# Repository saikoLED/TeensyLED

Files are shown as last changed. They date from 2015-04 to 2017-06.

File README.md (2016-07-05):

TeensyLED Controller
====================
Copyright Brian Neltner 2015<br/>
Version 0.4 - May 21, 2015

Summary
-------
This provides a basic library and example code for interacting
with a RGBW LED light using Hue, Saturation, and Intensity (HSI)
mode. Also provided are a basic USB interface example, and an example
for using the fully isolated DMX interface.

CircuitHub design created for this board with pre-identified working
parts. Licensed under CERN Open Hardware license (http://www.ohwr.org/projects/cernohl) which
allows for anyone to copy, modify and distribute this design (and products manufactured therefrom) so long
as they are licensed under identical terms & maintain all copyrights.

https://circuithub.com/projects/neltnerb/TeensyLED

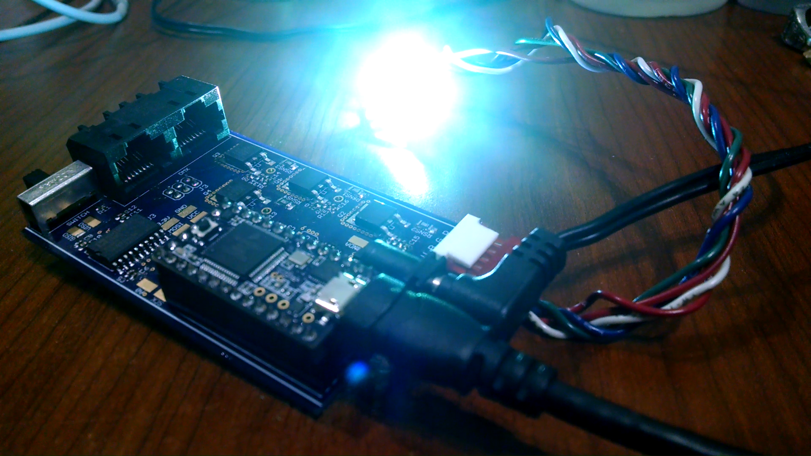
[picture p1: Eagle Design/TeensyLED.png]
Board Image


Software Features
-----------------
- HSI to RGBW library for interacting with LED sources with color correction.
- PID based fader that follows a random walk through colorspace.
- Tested basic DMX receiving software (just prints DMX data to USB Serial port for now).
- Basic debug example to set the brightness from the USB port.

For more information about the HSI Colorspace developed by SaikoLED
please check out:
- [Why every LED light should be using HSI colorspace.](http://blog.saikoled.com/post/43693602826/why-every-led-light-should-be-using-hsi)
- [How to convert from HSI to RGB+white.](http://blog.saikoled.com/post/44677718712/how-to-convert-from-hsi-to-rgb-white)
- [Implementing arbitrary color correction with the myki!](http://blog.saikoled.com/post/45630908157/implementing-arbitrary-color-correction-with-the)
- [Talk about HSI Colorspace and RGBW](http://blog.saikoled.com/post/71708131057/talk-about-hsi-colorspace-and-rgbw)

If you are curious about our other projects, you can visit our [blog](http://blog.saikoled.com).

Hardware Features
-----------------

[Schematics and Board Drawings](Eagle Design/TeensyLED.pdf)

- Teensy 3.1 socket.
- RJ45-based DMX Connectors as per DMX-512A.
- Fully isolated DMX-compatible RS485 Interface (ADM2582E).
- Header to switch polarity of DMX signal for compatibility.
- 4x 700mA BJT based current sinks (670-730mA typical).
- Current sinks capable of driving 700mA with 75ns pulse widths.
- 75nm pulse width allows 16-bit PWM at 183Hz, or 8-bit PWM at very fast. 16-bit PWM possible at higher PWM frequencies, but with increased non-linearity for low codes. See Simulations directory for more detail on theoretical performance.
- 5-24VDC board compatibility, with the Vin routed directly to LED V+. Up to 5A allowed by CP-202AH-ND barrel plug connector. Voltage limit is due to barrel plug connector, up to 48VDC can be wired directly using the available test point.
- Built in high efficiency switching regulator to provide 3.7VDC.
- Designed to fit into Hammond 1455C801 Extruded Aluminum Enclosure.
- 8-pin expansion header to access 3.3V, GND, DAC, A0 (SCK), A1/A2 (Touch), and DIN/DOUT (SPI/USART).
- PTC Fuse to prevent damage from shorts or over-power.
- Reverse protection diodes on power inlet and flyback diodes on each LED output to prevent reverse bias.

Hardware Performance
--------------------
Simulations have been done on the current sinking circuitry in order to optimize the response time and stability, and real measurements demonstrate comparable performance. Simulations were done using LTSpice and the vendor supplied model for the ZXT1053AK. These simulations are limited in predicting real performance, particularly in the realm of thermal issues.

###Circuit Model
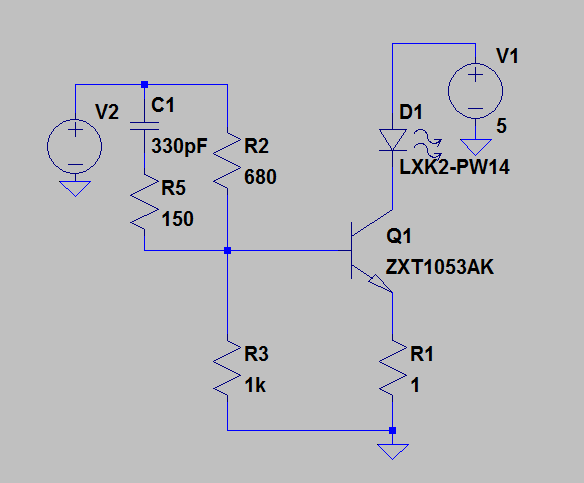
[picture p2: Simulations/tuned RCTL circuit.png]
Circuit Schematic


###Current Output with 1μs pulse.
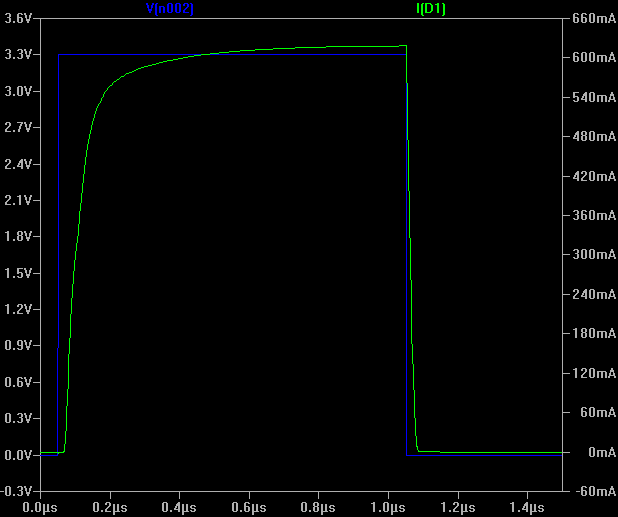
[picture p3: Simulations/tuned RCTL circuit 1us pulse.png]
1μs Pulse Width


###Current Output with 100ns pulse.
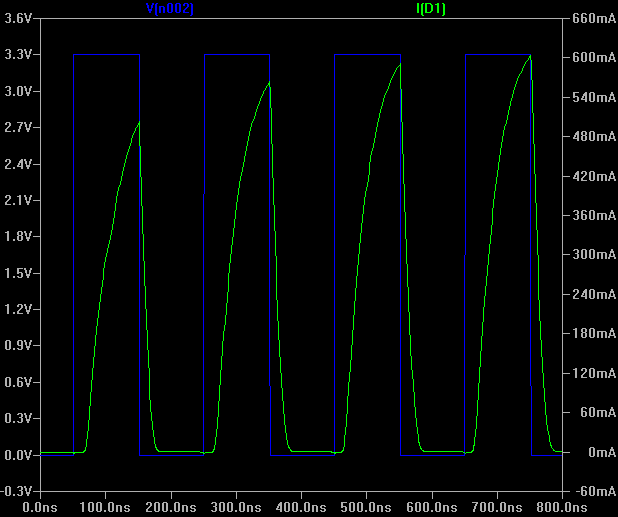
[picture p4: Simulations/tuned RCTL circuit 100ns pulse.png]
100ns Pulse Width


###Estimated current load from controller pin.
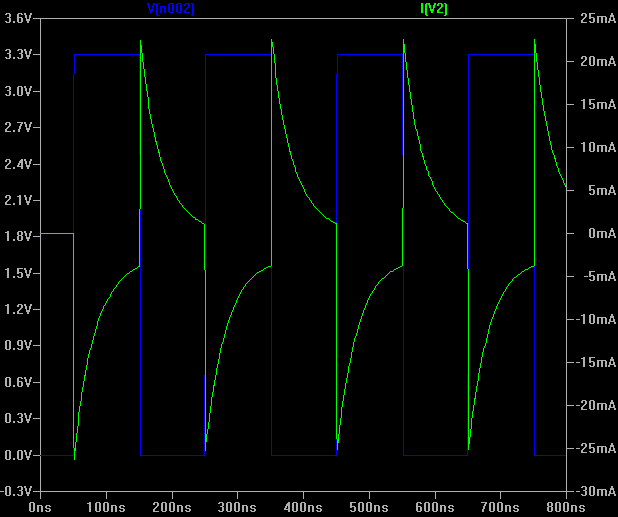
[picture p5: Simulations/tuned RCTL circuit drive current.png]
Drive Current


Major Hardware Limitations
--------------------------
- Heat dissipation at the BJTs is the primary limiting factor on maximum power. Switching regulators
are unfortunately inappropriate for such high speed PWM capabilities.
  - Although the BJTs chosen are rated to 4.4W each, at 700mA and a
    typical minimum drop from the top of the BJT to ground of 3V for
    good regulation, power dissipation throughout the board is likely
    to be a bare minimum of 2.1W per channel fully on.
  - I think that if you operate the system in HSI mode, where the
    total current sent to the LEDs is limited to 700mA, split between
    the various channels to change colors, you can probably get away
    with as much as 4W from that subsystem. This is power lost in the
    current sink itself, the power of the LEDs is unimportant.
  - This limits the voltage you can have between the *bottom* of your
    LED chain (no matter how long it is) and ground to under *5VDC*.
  - I am thinking about a new design that will automatically regulate
    down the voltage at the top of the LEDs to the minimum needed
    for reliable regulation based on feedback, but this is a work in
    progress. Perhaps for version 2.0.
- High current and high frequency PWM may radiate excessively for FCC. There is a ferrite bead to improve FCC compatibility, but the wiring between this board and the LEDs will be a significant radiator and must be done with care if the result is intended for sale.
- High current and frequency PWM may degrade ADC measurements, especially from high-
    impedance sources.

License
-------
All software, hardware designs, and hardware design files are licensed
under the GPL.

> TeensyLED Controller is free software and hardware: you can redistribute
> it and/or modify it under the terms of the GNU General Public License
> as published by the Free Software Foundation, either version 3 of the
> License, or (at your option) any later version.
> 
> TeensyLED Controller is distributed in the hope that it will be useful,
> but WITHOUT ANY WARRANTY; without even the implied warranty of
> MERCHANTABILITY or FITNESS FOR A PARTICULAR PURPOSE.  See the
> GNU General Public License for more details.
> 
> You should have received a copy of the GNU General Public License
> along with TeensyLED Controller.  If not, see <http://www.gnu.org/licenses/>.

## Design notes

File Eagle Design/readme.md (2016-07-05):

Board Design files for TeensyLED (EagleCad).

CircuitHub populated design that you may use to produce copies of this board.
https://circuithub.com/projects/neltnerb/TeensyLED

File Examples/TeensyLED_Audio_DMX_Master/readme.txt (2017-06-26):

TeensyLED Audio DMX Master
Version 0.9
Copyright Brian Neltner 2016

Video Example Demonstrating Algorithm Functionality with Color Kinetics ColorBlast 12.
https://www.youtube.com/watch?v=BOnsDaA30Ak

Description:

This program is designed for use with the SaikoLED TeensyLED Driver
system, using the ADM2582E from Analog Devices to provide a fully
isolated RS485/DMX-512 interface which has been demonstrated as both
a DMX master and DMX slave device.

TeensyLED Board Design Files (EagleCAD) and some other libraries can
be found at:
https://github.com/saikoLED/TeensyLED

A jumper is available on the TeensyLED board to allow switching between
the formal DMX-512a spec for DMX over RJ45/CAT5 cabling and the Color
Kinetics version of the standard, which switches DATA- and DATA+ and the
shield/ground connections.

Reference:
https://en.wikipedia.org/wiki/DMX512#RJ-45_pinout

This program assumes that line level audio (~1V peak-to-peak) is
available, and wired to analog input 0 on the Teensy 3.1 (on the
TeensyLED, this is available on JP1. In this example, A0 is connected
to 3.3V and GND via 100k resistors to provide a mid-scale DC offset
and then a capacitor is used to connect the audio input to AO.

As such, you end up with a capacitively coupled audio signal centered
at mid-scale. There are other ways to accomplish this with higher
fidelity, but for this purpose the audio quality is not particularly
important as it is never output to speakers and is only used for
controlling the lighting.

The basic algorithm below utilizes the SaikoLED HSI to RGB system to
convert a hue-saturation-intensity color to RGB which is then output
to standard RGB lighting. RGBW lighting could be used by switching
to the SaikoLED HSI->RGBW code, or using the new full CIE color
correction algorithm specifically designed to allow the TeensyLED to
control many-wavelength devices such as the LEDEngin LZ7 series LED
that provides RAGCBVW LEDs.

LEDEngin LZ7 LED and CIE Color Correction.
http://blog.saikoled.com/post/133625978643/full-cie-color-correction-with-the-teensy-31

For this audio analysis effect, the hue of the LED light is constantly
rotating, with beat detection utilized to cause pulses in the lighting.
Volume normalization is accomplished by saving the maximum audio signal
seen when the signal exceeds the prior maximum, but then gradually
letting the max signal level decay back to a low value over time so that
it can both immediately respond to volume increases, and recognize
when the audio has gotten quieter.

This effect also accomplishes automatic thresholding for the derivitive
of the audio signal for beat detection -- you select a target estimate
for the number of beats per second you'd like to see, and it gradually
tunes the threshold to the actual audio received to achieve roughly that
number of detection events. This works effectively to allow the user
to switch between very different music genres without needing to reprogram
a pile of magic constants to get it to look good.

Upon beat detection, the intensity of the lights immediately increases to
the normalized volume seen during that beat. As such, a loud beat in a soft
section of music will cause the light to flash brightly while a soft beat
in a loud section will appear more as a subtle flash. This results in a 
very nice effect wherein a loud beat followed by several soft accent beats
(very common in music of all kinds) shows the complexities of the beat
pattern very intuitively.

After a beat detection, the light brightness gradually decays -- the light
turning on is immediate but the decay takes ~100ms which gives a nice shape
that matches most drum signals very naturally. This decay time also varies
automatically based on the number of beats in the song. If a song has many
many beats the decay time is short so that the beats appear visually cleaner
to match the feeling of the music.

In this example code, I demonstrate controlling 8 DMX lights which are
arranged in a color wheel so that the entire array rotates around while
pulsing synchronously.

This rough algorithm was first demonstrated in 2013:
http://blog.saikoled.com/post/44823088119/myki-prototype-with-direct-audio-analysis
and the improved algorithm below was first demonstrated in 2016 at the
Firefly Arts Festival.

This software requires the DmxSimple library which uses bit-banging of
DMX outputs and does not support RDM or other advanced DMX features.
However, the ADM2582E and Teensy 3.1 should be perfectly capable of using
these features if a better library becomes available.

Filtering is used throughout this code, using explonential smoothing as a
very fast and simple way to accomplish a low-pass filter.

Reference:
https://en.wikipedia.org/wiki/Exponential_smoothing

An example is:

audioZero = 0.999999*audioZero + 0.000001*audioSignal;

which takes the prior zero and mixes it with the instantaneous
audio value to get a low-pass filtered zero. The two constants must
always add to one, but the larger the 0.000001 value is the more
quickly the filtered version will adjust to changes.

I am not good at C flags, but there are commented out serial communication
lines that can be uncommented for debug information (for instance, printing
the audio RMS values and beat detection values for tuning and debugging
audio signal issues). Some of this should probably be better encapsulated
in a C++ style class to reduce the unabstracted complexity of the effects.

Released under MIT License:

Copyright (c) 2016 Brian Neltner

Permission is hereby granted, free of charge, to any person obtaining a copy
of this software and associated documentation files (the "Software"), to deal
in the Software without restriction, including without limitation the rights
to use, copy, modify, merge, publish, distribute, sublicense, and/or sell
copies of the Software, and to permit persons to whom the Software is
furnished to do so, subject to the following conditions:

The above copyright notice and this permission notice shall be included in all
copies or substantial portions of the Software.

THE SOFTWARE IS PROVIDED "AS IS", WITHOUT WARRANTY OF ANY KIND, EXPRESS OR
IMPLIED, INCLUDING BUT NOT LIMITED TO THE WARRANTIES OF MERCHANTABILITY,
FITNESS FOR A PARTICULAR PURPOSE AND NONINFRINGEMENT. IN NO EVENT SHALL THE
AUTHORS OR COPYRIGHT HOLDERS BE LIABLE FOR ANY CLAIM, DAMAGES OR OTHER
LIABILITY, WHETHER IN AN ACTION OF CONTRACT, TORT OR OTHERWISE, ARISING FROM,
OUT OF OR IN CONNECTION WITH THE SOFTWARE OR THE USE OR OTHER DEALINGS IN THE
SOFTWARE.

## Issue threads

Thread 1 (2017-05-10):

Question ADM2582

kasperkamperman, 2017-05-10:
Hi,
Nice design. Maybe I'd like to make a similar kind of board for the Particle Photon. I was wondering why you have selected the ADM2582 and not the ADM2587. From what I can see in the datasheet the 2582 has a dataspeed of 16Mbps and the 2587 a dataspeed of 500kbps.

For DMX 500kbps will be sufficient I think because of the speed of 250000baud (250kbps).

Or do I miss something?

Thanks in advance for your feedback.

neltnerb, 2017-05-10:
Hi Kasper,

Yes! Please, the Photon looks great to me. I've built wifi lights before
since 2010:

http://www.instructables.com/id/Ultra-bright-LED-Color-Changing-Spotlight-using-Op/

but the photon looks like a way easier way to do it than what I've tried
before. I actually have a photon sitting on my desk that I just haven't
gotten around to modifying the TeensyLED board to handle. It shouldn't be
too challenging though, I think you should find it to not be a big problem.
I hope you share your design so that others can use it as well!

You may find helpful thinking about one thing ahead of time, which is wifi
latency. In my instructable project above, it is using a wifi chip running
on a local network, and even with only local communication with more than
about eight lights the latency became a problem. Lots of wifi devices on
one network has a lot of issues where one light will just sort of stop
getting updates for a bit and then start up again.

The biggest reason I have not yet tried the Photon for it is that because
the network is non-local (you, I believe, connect via their cloud service)
I can't make it work in remote locations like Burning Man and the latency
is much higher as the command to change colors has to traverse the internet
to make it to your lamp even if it's in the same room as you. I think you
can make the Photon communicate locally, but it didn't look as
straightforward as I had hoped.

There are two decent ways to work around this -- the first is to have a
single photon or only a few photons acting as DMX to WiFi Transceivers
which then send actual DMX commands out to a local network over physical
wires. This avoids wireless contention at least, and keeps at least the
lights on a single DMX universe synchronized. The second is to make the
lights very smart, and send them only very abstract commands like "do a
color wheel at this speed, saturation, and intensity" so that the amount of
data being sent to them is very small. Basically highly compressed data
rather than just an RGB color. Either approach works well, but you should
keep in mind both wireless contention and latency (particularly if it is
dealing with a non-local sever).

But I think you can do it! Please keep me updated, I would love to hear how
it goes!

With regards to the selection of the ADM2582E over the ADM2587E, I think
you are correct that the ADM2587E will work fine for DMX. I can't recall
for sure after the intervening years, but most likely the ADM2587E was out
of stock at the time so I just used the ADM2582E. I do not think there is
any reason it would not work just fine with the ADM2587E. There may even be
more appropriate chips now that it's three years later!

On Wed, May 10, 2017 at 3:24 AM, kasperkamperman <notifications@github.com>
wrote:

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

--
Brian Neltner, Ph.D.
President, SaikoLED
neltnerb@saikoled.com

kasperkamperman, 2017-05-11:
Hi Brian,

Thanks for the extensive response. I'm aware of the limitations of the Photon. Their main purpose is IoT, but you can use them in a local network as well (UDP/TCP). Latency with these kind of devices is always a problem. Although there is someone that build a ArtNet node with 8 universes with the STM32 processor (although it's a M4 variation and not the M3 as on the Photon) http://www.ulrichradig.de/home/index.php/dmx/8-kanal-art-net

My goal is however to generate DMX and effects on the Photon board itself (probably by using [FastLED](http://fastled.io) . I need to make a stable DMX output, but I found already some good implementations that I can use.

Of course I'll share the design and the library. If you'd like to follow along: https://community.particle.io/t/transmit-dmx-data-with-dma-on-serial1/32581

Another question. I see that you power the chip with 3.3V. I assumed that 5V was necessary. I was trying to find what the signal voltage of DMX is, since they follow the RS485 standard for the physical layer I think a difference of 200mV on the signal lines still gives a reliable data transmission (if I interpret the datasheet fine). I was wondering if 3.3V might do for long cable lengths because of cable resistance.

neltnerb, 2017-05-11:
Hi Kasper!

Sounds fabulous, I'm not sure I'd be able to help much with the DMX
code, but there are some good reference libraries.

I'm not myself a particularly skilled programmer, but you might check
out the actual reference implementations for DMX which exist for
several ARM processors.

http://www.nxp.com/documents/application_note/AN10717.pdf

for instance. NXP has several chips that they have application notes
and example code for DMX including RDM. I don't think I'd be capable of
porting it, but perhaps you can!

The signal voltage for DMX is the same as the signal voltage for RS485,
balanced +/- 200mV. The reason I picked the ADM2582E is because it has
a built in isolated voltage transformer to power the isolated half
without needing additional transformers, so it produces the 200mV
signal level internally. No need to think much about it.

The 3.3V sets the interface voltage, so I matched the interface voltage
expected by the Teensy board. So just match whatever the Photon expects
(probably 3.3V). It will generate it's own transceiver voltages.

The interface being isolated from the board grounds is pretty critical.
If you don't do it you end up with horrific ground loops if you have
multiple lights connected to different voltage grounds. A lot of cheap
commercial LED fixtures don't do this properly and it causes I'd say
the majority of communications failures in installations.

But check out my eagle files for how to make sure the ground planes are
separated, if you connect the grounds between the RS485 and the rest of
the board it will defeat the purpose of using the ADM2582E because it
will just re-connect the grounds and re-create the ground loops.

I'll also warn you that Color Kinetics fixtures use a non-standard DMX
wiring layout. It's mentioned in the wikipedia page I believe but
you'll need a way to switch between the two pinouts if you want to use
both them and devices implementing the official standard.

kasperkamperman, 2017-05-12:
Thanks!

Closed 2017-05-12.

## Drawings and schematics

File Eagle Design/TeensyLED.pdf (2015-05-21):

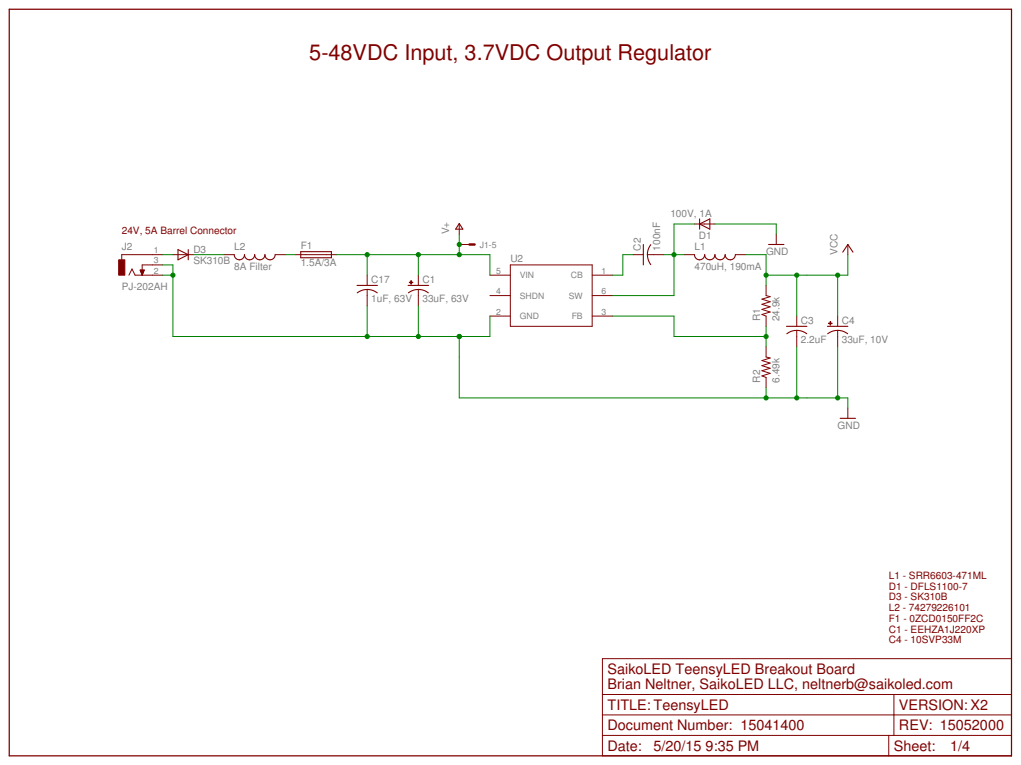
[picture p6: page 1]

SaikoLED TeensyLED Breakout Board
Brian Neltner, SaikoLED LLC, neltnerb@saikoled.com

TITLE: TeensyLED | VERSION: X2
Document Number: 15041400 | REV: 15052000
Date: 5/20/15 9:35 PM | Sheet: 1/4

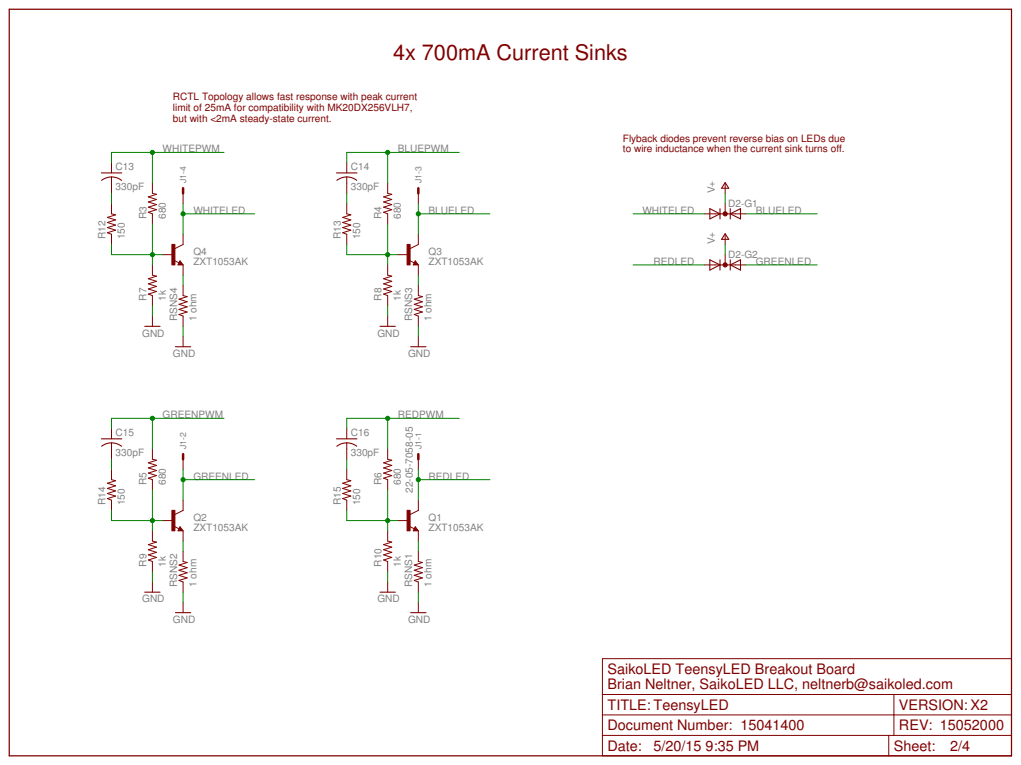
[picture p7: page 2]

RCTL Topology allows fast response with peak current

to wire inductance when the current sink turns off.

SaikoLED TeensyLED Breakout Board
Brian Neltner, SaikoLED LLC, neltnerb@saikoled.com

TITLE: TeensyLED | VERSION: X2
Document Number: 15041400 | REV: 15052000

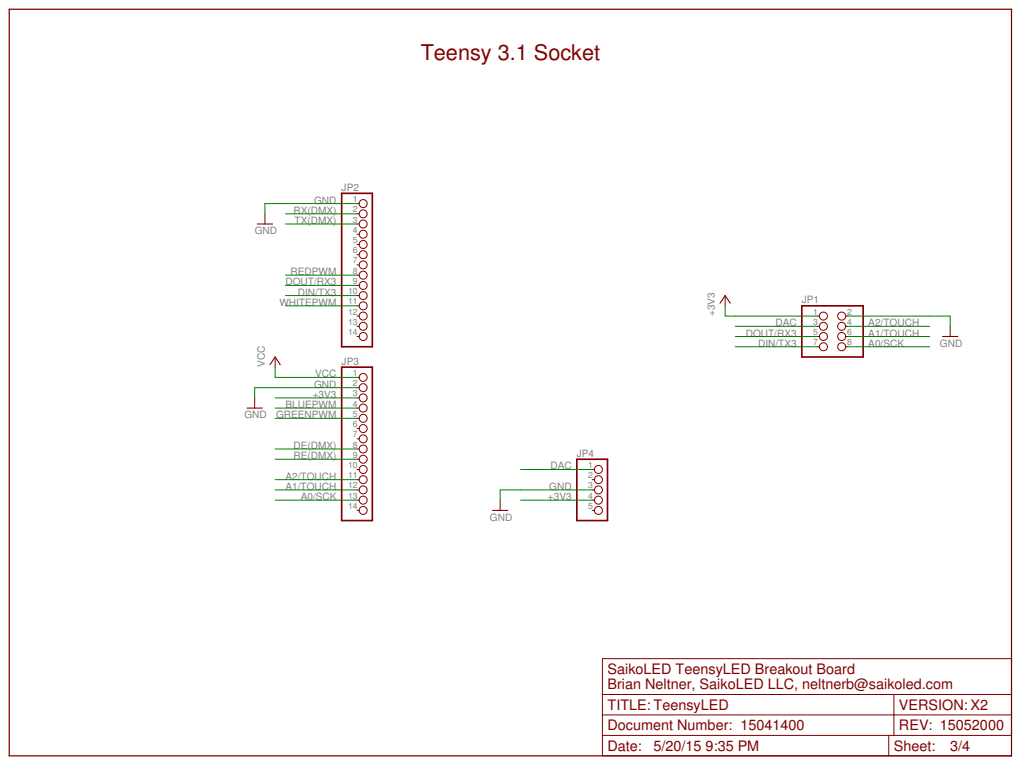
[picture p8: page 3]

SaikoLED TeensyLED Breakout Board
Brian Neltner, SaikoLED LLC, neltnerb@saikoled.com

TITLE: TeensyLED | VERSION: X2
Document Number: 15041400 | REV: 15052000

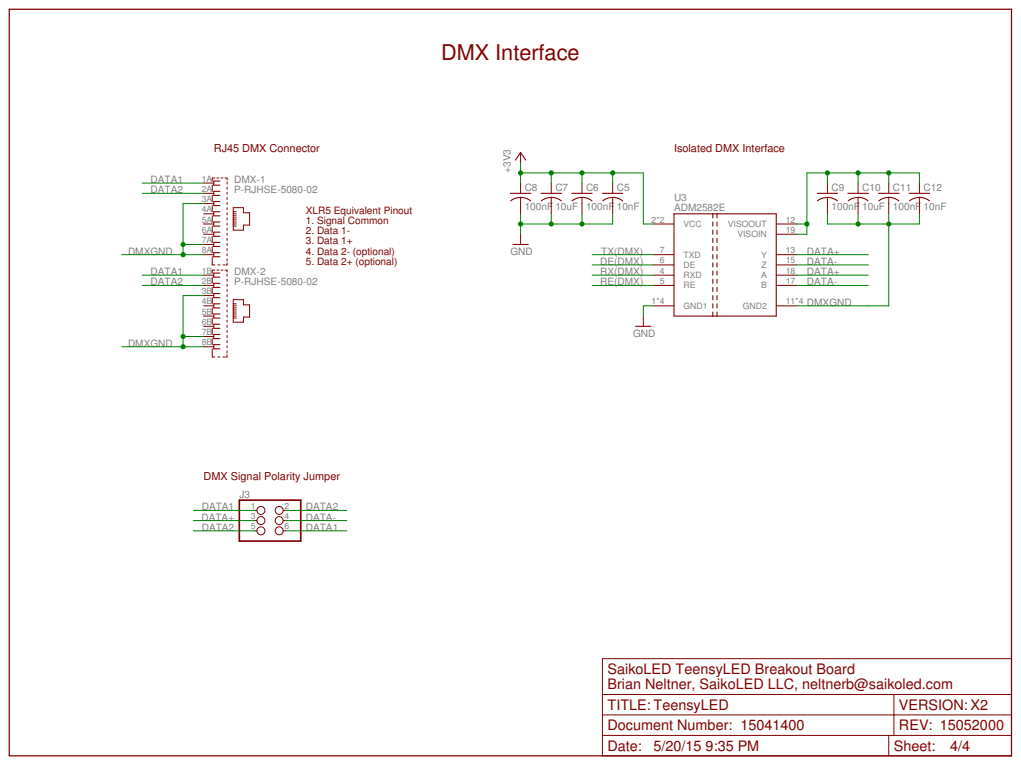
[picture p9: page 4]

DMX Signal Polarity Jumper

SaikoLED TeensyLED Breakout Board
Brian Neltner, SaikoLED LLC, neltnerb@saikoled.com

TITLE: TeensyLED | VERSION: X2
Document Number: 15041400 | REV: 15052000

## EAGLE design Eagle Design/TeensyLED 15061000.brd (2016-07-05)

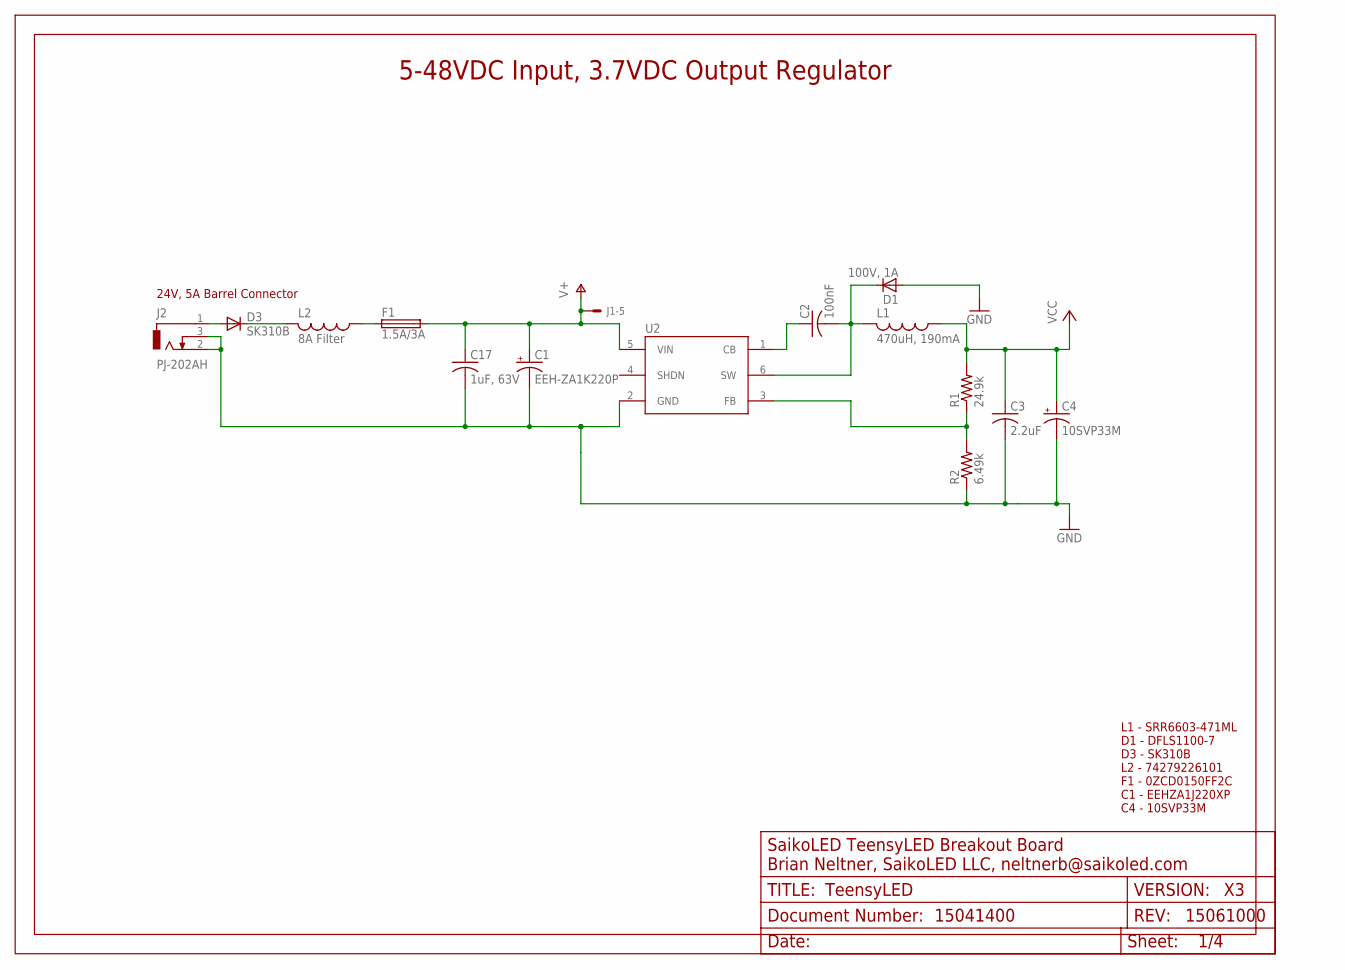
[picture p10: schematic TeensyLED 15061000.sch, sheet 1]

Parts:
C1: EEH-ZA1K220P; PANASONIC_F
C2: 100nF; C0805K
C3: 2.2uF; C0402PRO; MPN MCLV4R7M1HB-0513-RH
C4: 10SVP33M; PANASONIC_B
C17: 1uF, 63V; C0805K; MPN MCLV4R7M1HB-0513-RH
D1: 100V, 1A; DFLS1100
D3: SK310B; SMB
F1: 1.5A/3A; 2920
FRAME1: LETTER_LNOSILK; EMPTY
J1: 22-05-7058-05; 7395-05
J2: PJ-202AH
L1: 470uH, 190mA; SRR6603
L2: 8A Filter; L1812
R1: 24.9k; R0402PRO; MPN BLU0402-9762-BT25W
R2: 6.49k; R0402PRO; MPN ERJ-3EKF4123V
U2: LMR16006YDDCT; DDC0006A; MPN MCF 0.25W 1K

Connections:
GND: C1.-, C3.2, C4.-, C17.2, D1.A, J2.2 (3), J2.3 (2), R2.1, U2.2 (GND); also elsewhere on the board
unnamed: C2.1, U2.1 (CB)
unnamed: F1.P$1 (1), L2.1
unnamed: R1.1, R2.2, U2.3 (FB)
unnamed: D3.C, L2.2
unnamed: D3.A, J2.1
V+: C1.+, C17.1, F1.P$2 (2), J1.5, U2.5 (VIN); also elsewhere on the board
VCC: C3.1, C4.+, L1.P$1 (1), R1.2; also elsewhere on the board
VSW: C2.2, D1.C, L1.P$2 (2), U2.6 (SW)

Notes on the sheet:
5-48VDC Input, 3.7VDC Output Regulator
24V, 5A Barrel Connector
L1 - SRR6603-471ML D1 - DFLS1100-7 D3 - SK310B L2 - 74279226101 F1 - 0ZCD0150FF2C C1 - EEHZA1J220XP C4 - 10SVP33M

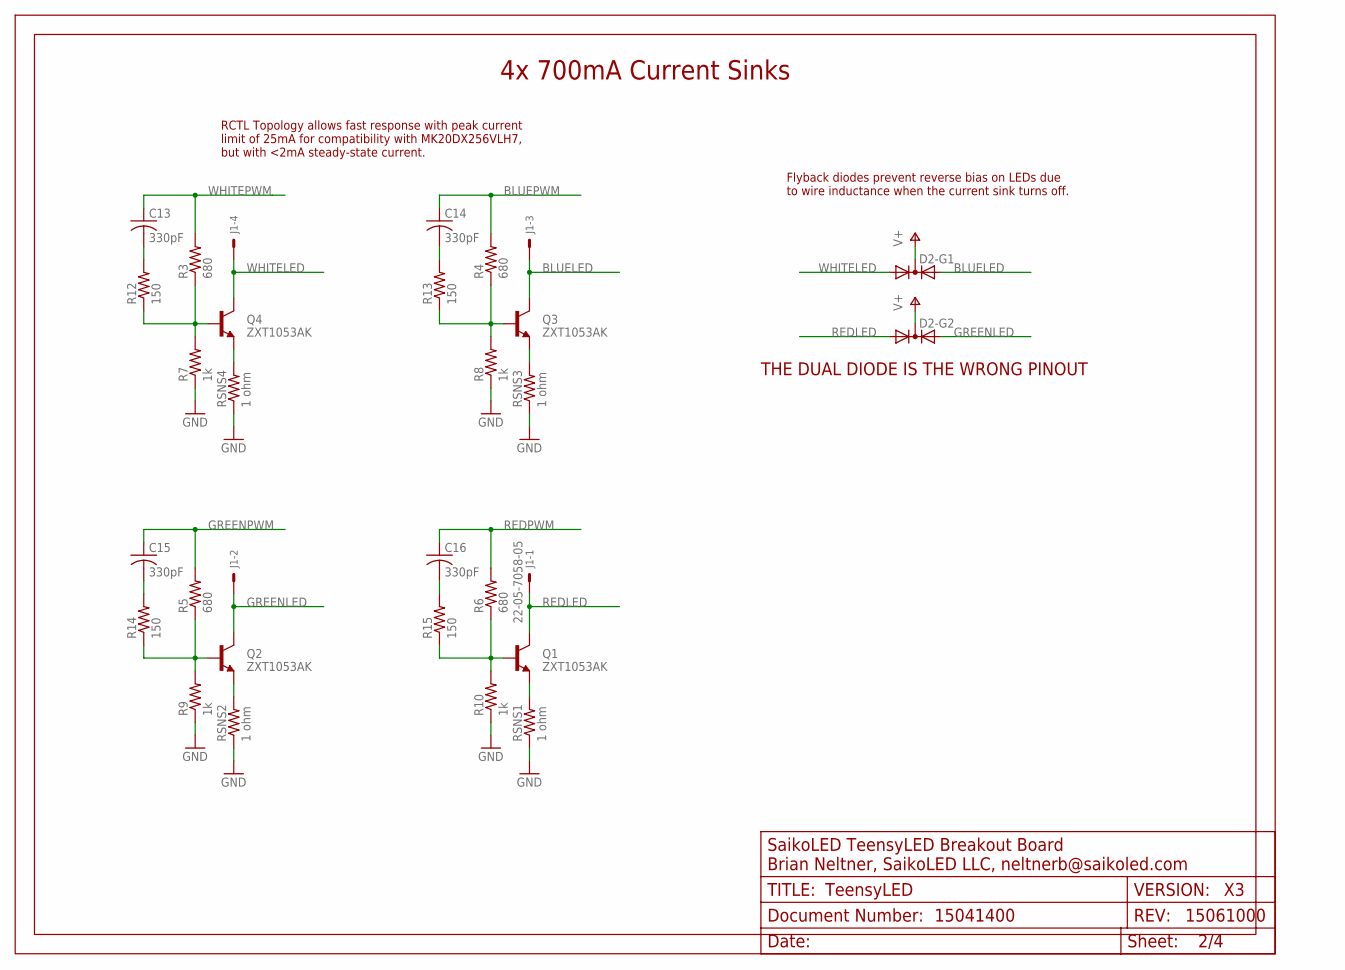
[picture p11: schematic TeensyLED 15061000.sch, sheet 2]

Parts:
C13, C14, C15, C16: 330pF; C0402PRO
D2: DUAL_DIODE_AC-CA-SOT363; SOT363_PHILIPS
FRAME2: LETTER_LNOSILK; EMPTY
J1: 22-05-7058-05; 7395-05
Q1, Q2, Q3, Q4: ZXT1053AK; TO252
R3, R4, R5, R6: 680; R0402PRO
R7, R8, R9, R10: 1k; R0402PRO
R12, R13, R14, R15: 150; R0402PRO
RSNS1, RSNS2, RSNS3, RSNS4: 1 ohm; R1206

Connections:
BLUELED: D2.3 (A2), J1.3, Q3.C
BLUEPWM: C14.1, R4.2; also elsewhere on the board
GND: R7.1, R8.1, R9.1, R10.1, RSNS1.1, RSNS2.1, RSNS3.1, RSNS4.1; also elsewhere on the board
GREENLED: D2.4 (A2), J1.2, Q2.C
GREENPWM: C15.1, R5.2; also elsewhere on the board
unnamed: Q2.E, RSNS2.2
unnamed: Q4.E, RSNS4.2
unnamed: Q3.E, RSNS3.2
unnamed: Q1.E, RSNS1.2
unnamed: Q2.B, R5.1, R9.2, R14.1
unnamed: Q4.B, R3.1, R7.2, R12.1
unnamed: Q1.B, R6.1, R10.2, R15.1
unnamed: C13.2, R12.2
unnamed: C14.2, R13.2
unnamed: C15.2, R14.2
unnamed: C16.2, R15.2
R23: Q3.B, R4.1, R8.2, R13.1
REDLED: D2.6 (A1), J1.1, Q1.C
REDPWM: C16.1, R6.2; also elsewhere on the board
V+: D2.2 (K), D2.5 (K); also elsewhere on the board
WHITELED: D2.1 (A1), J1.4, Q4.C
WHITEPWM: C13.1, R3.2; also elsewhere on the board

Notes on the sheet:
4x 700mA Current Sinks
RCTL Topology allows fast response with peak current limit of 25mA for compatibility with MK20DX256VLH7, but with <2mA steady-state current.
Flyback diodes prevent reverse bias on LEDs due to wire inductance when the current sink turns off.
THE DUAL DIODE IS THE WRONG PINOUT

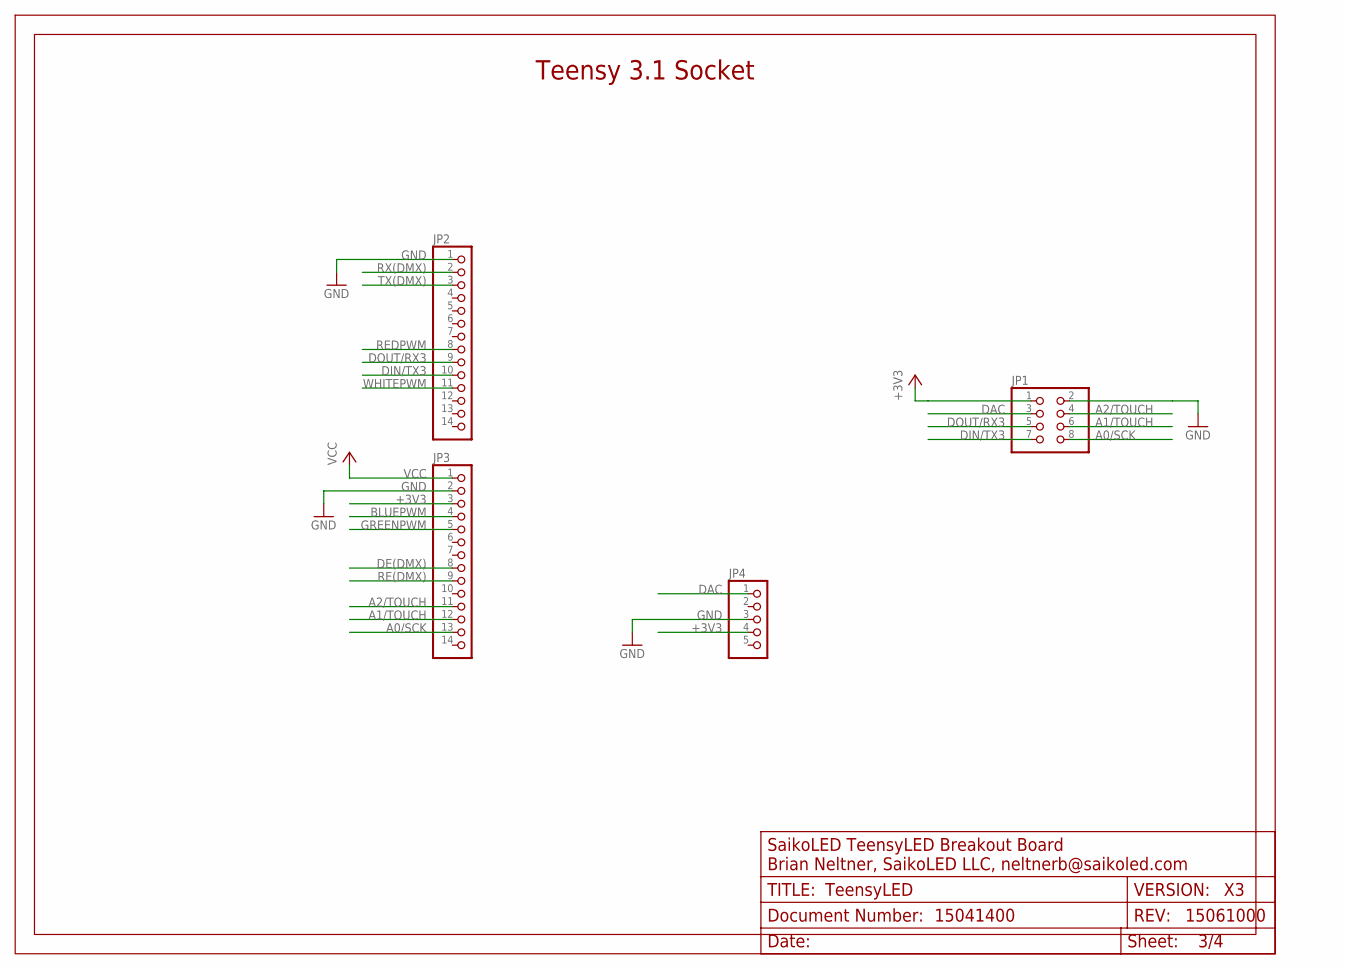
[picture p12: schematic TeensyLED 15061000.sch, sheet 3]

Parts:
FRAME3: LETTER_LNOSILK; EMPTY
JP1: PINHD-2X4; 2X04
JP2, JP3: PINHD-1X14/ROUND; 1X14/ROUND
JP4: PINHD-1X5/ROUND; 1X05/ROUND

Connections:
+3V3: JP1.1, JP3.3, JP4.4; also elsewhere on the board
A0/SCK: JP1.8, JP3.13
A1/TOUCH: JP1.6, JP3.12
A2/TOUCH: JP1.4, JP3.11
BLUEPWM: JP3.4; also elsewhere on the board
DAC: JP1.3, JP4.1
DE(DMX): JP3.8; also elsewhere on the board
DIN/TX3: JP1.7, JP2.10
DOUT/RX3: JP1.5, JP2.9
GND: JP1.2, JP2.1, JP3.2, JP4.3; also elsewhere on the board
GREENPWM: JP3.5; also elsewhere on the board
RE(DMX): JP3.9; also elsewhere on the board
REDPWM: JP2.8; also elsewhere on the board
RX(DMX): JP2.2; also elsewhere on the board
TX(DMX): JP2.3; also elsewhere on the board
VCC: JP3.1; also elsewhere on the board
WHITEPWM: JP2.11; also elsewhere on the board

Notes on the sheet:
Teensy 3.1 Socket

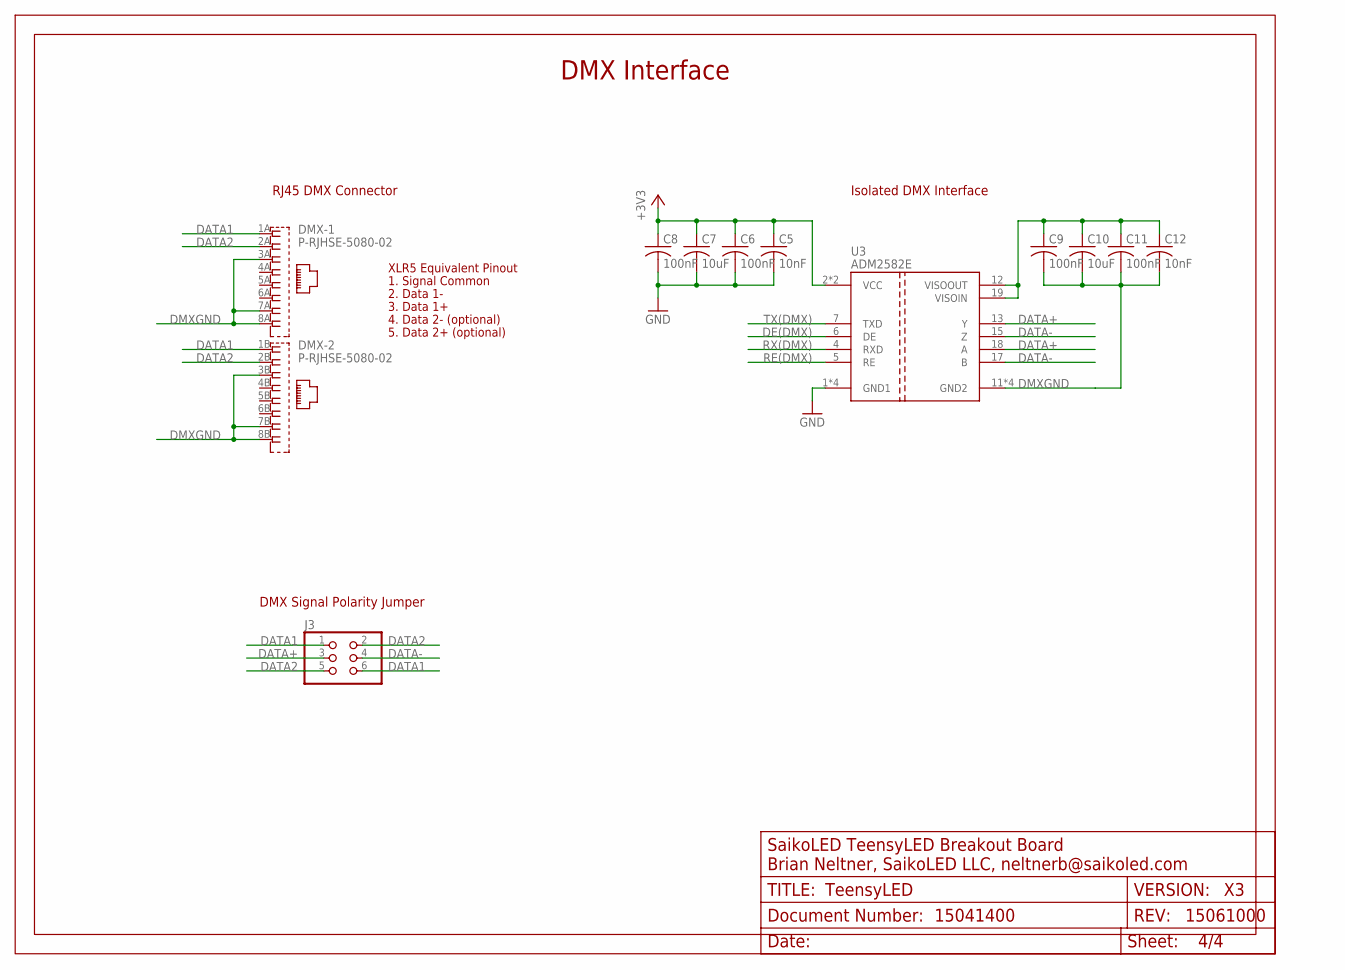
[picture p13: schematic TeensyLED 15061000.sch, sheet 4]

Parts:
C5, C12: 10nF; C0402PRO
C6, C8, C9, C11: 100nF; C0402PRO
C7, C10: 10uF; C0402PRO
DMX: P-RJHSE-5080-02
FRAME4: LETTER_LNOSILK; EMPTY
J3: PINHD-2X3; 2X03
U3: ADM2582E; SO-20DW

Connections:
+3V3: C5.1, C6.1, C7.1, C8.1, U3.2 (VCC), U3.8 (VCC); also elsewhere on the board
DATA1: DMX.1A (1), DMX.1B (1), J3.1, J3.6
DATA2: DMX.2A (2), DMX.2B (2), J3.2, J3.5
DATA+: J3.3, U3.13 (Y), U3.18 (A)
DATA-: J3.4, U3.15 (Z), U3.17 (B)
DE(DMX): U3.6 (DE); also elsewhere on the board
DMXGND: C9.2, C10.2, C11.2, C12.2, DMX.3A (3), DMX.3B (3), DMX.7A (7), DMX.7B (7), DMX.8A (8), DMX.8B (8), U3.11 (GND2), U3.14 (GND2), U3.16 (GND2), U3.20 (GND2)
GND: C5.2, C6.2, C7.2, C8.2, U3.1 (GND1), U3.3 (GND1), U3.9 (GND1), U3.10 (GND1); also elsewhere on the board
unnamed: C9.1, C10.1, C11.1, C12.1, U3.12 (VISOOUT), U3.19 (VISOIN)
RE(DMX): U3.5 (RE); also elsewhere on the board
RX(DMX): U3.4 (RXD); also elsewhere on the board
TX(DMX): U3.7 (TXD); also elsewhere on the board

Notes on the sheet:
XLR5 Equivalent Pinout
1. Signal Common
2. Data 1-
3. Data 1+
4. Data 2- (optional)
5. Data 2+ (optional)
Isolated DMX Interface
DMX Signal Polarity Jumper
RJ45 DMX Connector
DMX Interface

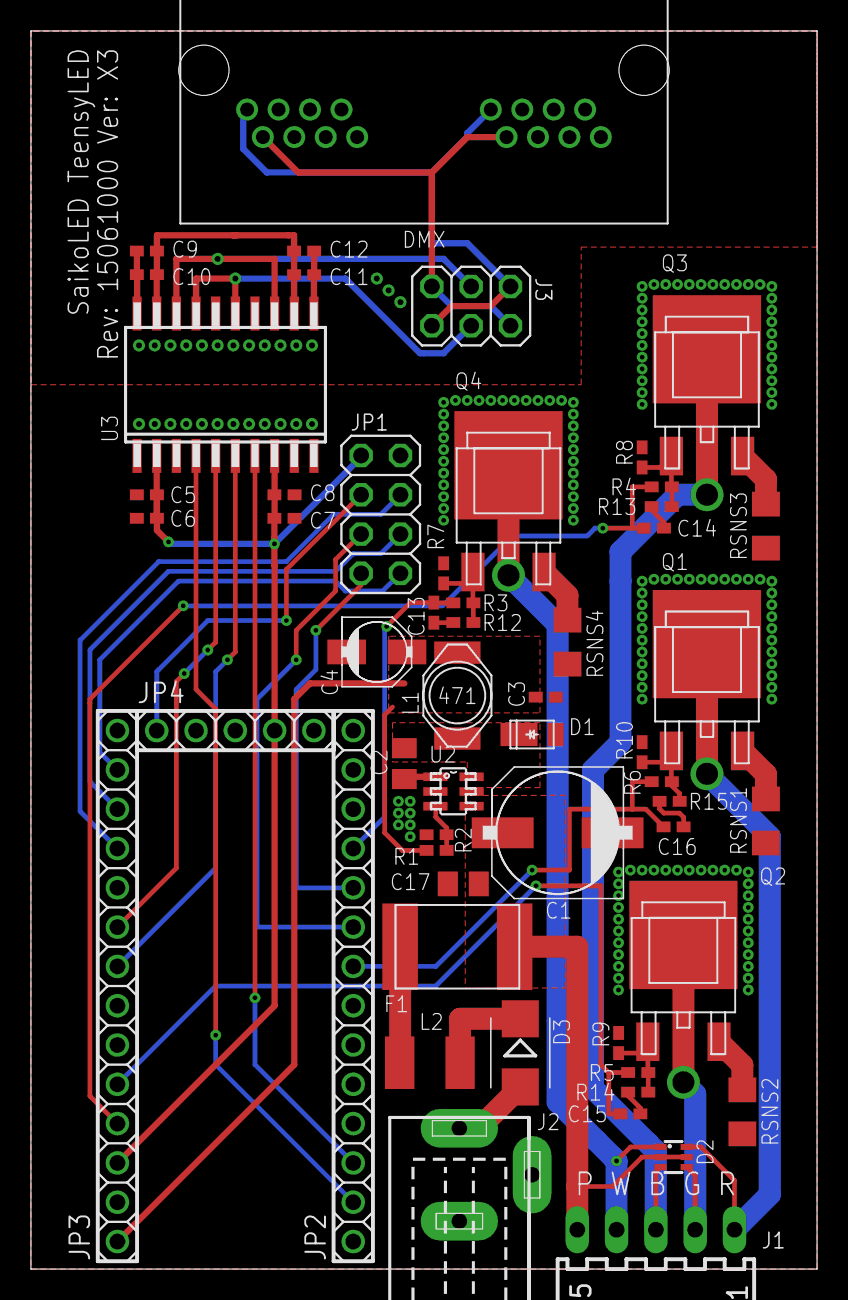
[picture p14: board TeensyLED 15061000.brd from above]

Board: 2 copper layers, 50.8 x 80.0 mm, 59 parts (0 on the bottom side), 46 nets.

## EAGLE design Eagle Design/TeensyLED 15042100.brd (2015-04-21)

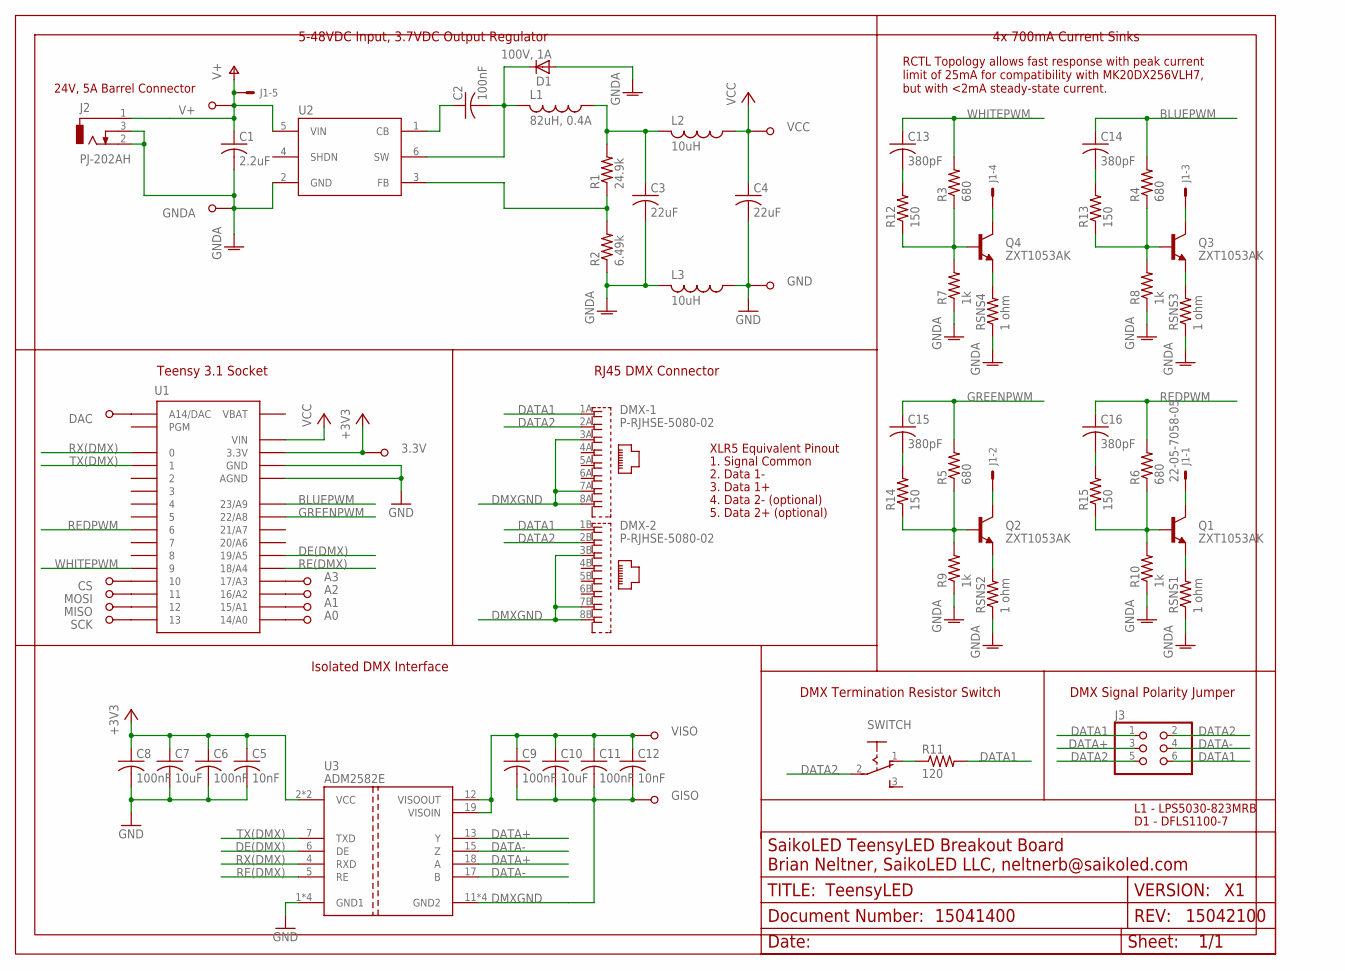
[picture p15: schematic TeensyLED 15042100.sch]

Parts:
3.3V: TESTPOINT5019; 5019
A0, A1, A2, A3: TESTPOINT5019; 5019
C1: 2.2uF; C1210K
C2: 100nF; C0805K
C3: 22uF; C0805K; MPN MCLV4R7M1HB-0513-RH
C4: 22uF; C0805K
C5, C12: 10nF; C0402PRO
C6, C8, C9, C11: 100nF; C0402PRO
C7, C10: 10uF; C0402PRO
C13, C14, C15, C16: 380pF; C0402PRO
CS: TESTPOINT5019; 5019
D1: 100V, 1A; DFLS1100
DAC: TESTPOINT5019; 5019
DMX: P-RJHSE-5080-02
FRAME1: LETTER_L; PCBINFO
GISO: TESTPOINT5019; 5019
GND: TESTPOINT5019; 5019
GNDA: TESTPOINT5019; 5019
J1: 22-05-7058-05; 7395-05
J2: PJ-202AH
J3: PINHD-2X3; 2X03
L1: 82uH, 0.4A; LPS5030
L2, L3: 10uH; L2012C
MISO: TESTPOINT5019; 5019
MOSI: TESTPOINT5019; 5019
Q1, Q2, Q3, Q4: ZXT1053AK; TO252
R1: 24.9k; R0402PRO; MPN BLU0402-9762-BT25W
R2: 6.49k; R0402PRO; MPN ERJ-3EKF4123V
R3, R4, R5, R6: 680; R0402PRO
R7, R8, R9, R10: 1k; R0402PRO
R11: 120; R0402PRO
R12, R13, R14, R15: 150; R0402PRO
RSNS1, RSNS2, RSNS3, RSNS4: 1 ohm; R1206
SCK: TESTPOINT5019; 5019
SWITCH: M251; SK-12F17-G
U1: TEENSY_3.0_BASIC
U2: LMR16006YDDCT; DDC0006A; MPN MCF 0.25W 1K
U3: ADM2582E; SO-20DW
V+: TESTPOINT5019; 5019
VCC: TESTPOINT5019; 5019
VISO: TESTPOINT5019; 5019

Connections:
+3V3: 3.3V.P$1, C5.1, C6.1, C7.1, C8.1, U1.3.3V, U1.3.3V1 (3.3V), U3.2 (VCC), U3.8 (VCC)
BLUEPWM: C14.1, R4.2, U1.23/A9
DATA1: DMX.1A (1), DMX.1B (1), J3.1, J3.6, R11.2
DATA2: DMX.2A (2), DMX.2B (2), J3.2, J3.5, SWITCH.2
DATA+: J3.3, U3.13 (Y), U3.18 (A)
DATA-: J3.4, U3.15 (Z), U3.17 (B)
DE(DMX): U1.19/A5, U3.6 (DE)
DMXGND: C9.2, C10.2, C11.2, C12.2, DMX.3A (3), DMX.3B (3), DMX.7A (7), DMX.7B (7), DMX.8A (8), DMX.8B (8), GISO.P$1, U3.11 (GND2), U3.14 (GND2), U3.16 (GND2), U3.20 (GND2)
GND: C4.2, C5.2, C6.2, C7.2, C8.2, GND.P$1, L3.1, U1.AGND, U1.GND, U1.GND1 (GND), U3.1 (GND1), U3.3 (GND1), U3.9 (GND1), U3.10 (GND1)
GNDA: C1.2, C3.2, D1.A, GNDA.P$1, J2.2 (3), J2.3 (2), L3.2, R2.1, R7.1, R8.1, R9.1, R10.1, RSNS1.1, RSNS2.1, RSNS3.1, RSNS4.1, U2.2 (GND)
GREENPWM: C15.1, R5.2, U1.22/A8
unnamed: C2.2, D1.C, L1.P$2 (2), U2.6 (SW)
unnamed: C2.1, U2.1 (CB)
unnamed: J1.3, Q3.C
unnamed: DAC.P$1, U1.RESET (A14/DAC)
unnamed: R1.1, R2.2, U2.3 (FB)
unnamed: J1.1, Q1.C
unnamed: J1.2, Q2.C
unnamed: Q2.E, RSNS2.2
unnamed: C3.1, L1.P$1 (1), L2.2, R1.2
unnamed: C9.1, C10.1, C11.1, C12.1, U3.12 (VISOOUT), U3.19 (VISOIN), VISO.P$1
unnamed: Q4.E, RSNS4.2
unnamed: Q3.E, RSNS3.2
unnamed: A0.P$1, U1.14/A0
unnamed: R11.1, SWITCH.1 (O)
unnamed: Q1.E, RSNS1.2
unnamed: Q2.B, R5.1, R9.2, R14.1
unnamed: A1.P$1, U1.15/A1
unnamed: A2.P$1, U1.16/A2
unnamed: A3.P$1, U1.17/A3
unnamed: Q4.B, R3.1, R7.2, R12.1
unnamed: CS.P$1, U1.10
unnamed: Q1.B, R6.1, R10.2, R15.1
unnamed: MOSI.P$1, U1.11
unnamed: MISO.P$1, U1.12
unnamed: SCK.P$1, U1.13
unnamed: C13.2, R12.2
unnamed: C14.2, R13.2
unnamed: C15.2, R14.2
unnamed: C16.2, R15.2
Q4: J1.4, Q4.C
R23: Q3.B, R4.1, R8.2, R13.1
RE(DMX): U1.18/A4, U3.5 (RE)
REDPWM: C16.1, R6.2, U1.6
RX(DMX): U1.0, U3.4 (RXD)
TX(DMX): U1.1, U3.7 (TXD)
V+: C1.1, J1.5, J2.1, U2.5 (VIN), V+.P$1
VBAT: U1.VBAT
VCC: C4.1, L2.1, U1.VIN, VCC.P$1
WHITEPWM: C13.1, R3.2, U1.9

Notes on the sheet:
L1 - LPS5030-823MRB
D1 - DFLS1100-7
XLR5 Equivalent Pinout
1. Signal Common
2. Data 1-
3. Data 1+
4. Data 2- (optional)
5. Data 2+ (optional)
DMX Termination Resistor Switch
Isolated DMX Interface
DMX Signal Polarity Jumper
RJ45 DMX Connector
4x 700mA Current Sinks
Teensy 3.1 Socket
5-48VDC Input, 3.7VDC Output Regulator
RCTL Topology allows fast response with peak current limit of 25mA for compatibility with MK20DX256VLH7, but with <2mA steady-state current.
24V, 5A Barrel Connector

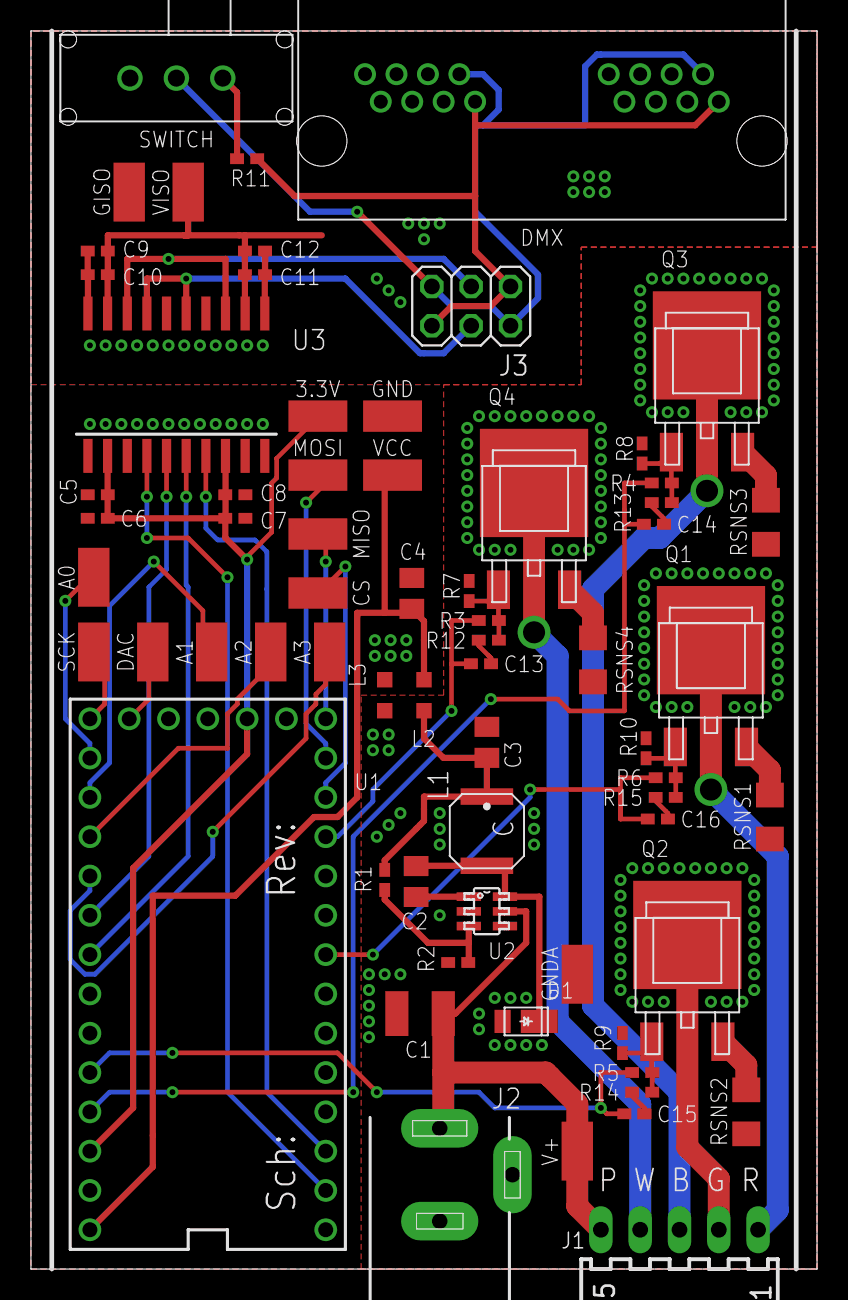
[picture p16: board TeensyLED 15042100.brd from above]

Board: 2 copper layers, 50.8 x 80.0 mm, 68 parts (0 on the bottom side), 49 nets.

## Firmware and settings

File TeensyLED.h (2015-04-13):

//*********************************************************
//
// TeensyLED Controller Library
// Copyright Brian Neltner 2015
// Version 0.1 - April 13, 2015
//
// This file is part of TeensyLED Controller.
//
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
//**********************************************************

#include <Arduino.h>

class RGBWLamp {
  protected:
    char _redpin, _greenpin, _bluepin, _whitepin;
    float _hue, _saturation, _intensity;
  public:
    RGBWLamp(char redpin, char greenpin, char bluepin, char whitepin, char resolution, unsigned long PWMfrequency);
    void setHue(float hue) {
      _hue = fmod(hue, 360);
    };
    void setSaturation(float S) {
      _saturation = S>0?(S<1?S:1):0;
    };
    void setIntensity(float I) {
      _intensity = I>0?(I<1?I:1):0;
    }
    void setColor(void);
    float getHue(void) {return _hue;};
    float getSaturation(void) {return _saturation;};
    float getIntensity(void) {return _intensity;};
};

RGBWLamp::RGBWLamp(char redpin, char greenpin, char bluepin, char whitepin, char resolution, unsigned long PWMfrequency) :
  _redpin(redpin),
  _greenpin(greenpin),
  _bluepin(bluepin),
  _whitepin(whitepin),
  _hue(0),
  _saturation(1),
  _intensity(0) {
    pinMode(_redpin, OUTPUT);
    pinMode(_greenpin, OUTPUT);
    pinMode(_bluepin, OUTPUT);
    pinMode(_whitepin, OUTPUT);
    analogWriteFrequency(_redpin, PWMfrequency);
    analogWriteFrequency(_greenpin, PWMfrequency);
    analogWriteFrequency(_bluepin, PWMfrequency);
    analogWriteFrequency(_whitepin, PWMfrequency);
    analogWriteResolution(resolution);
}

void RGBWLamp::setColor(void) {
  float r, g, b, w;
  float H = _hue;
  float S = _saturation;
  float I = _intensity;
  float cos_h, cos_1047_h;
  H = 3.14159*H/(float)180; // Convert to radians.
  
  // This section is modified by the addition of white so that it assumes 
  // fully saturated colors, and then scales with white to lower saturation.
  //
  // Next, scale appropriately the pure color by mixing with the white channel.
  // Saturation is defined as "the ratio of colorfulness to brightness" so we will
  // do this by a simple ratio wherein the color values are scaled down by (1-S)
  // while the white LED is placed at S.
  
  // This will maintain constant brightness because in HSI, R+B+G = I. Thus, 
  // S*(R+B+G) = S*I. If we add to this (1-S)*I, where I is the total intensity,
  // the sum intensity stays constant while the ratio of colorfulness to brightness
  // goes down by S linearly relative to total Intensity, which is constant.

  if(H < 2.09439) {
    cos_h = cos(H);
    cos_1047_h = cos(1.047196667-H);
    r = S*I/3*(1+cos_h/cos_1047_h);
    g = S*I/3*(1+(1-cos_h/cos_1047_h));
    b = 0;
    w = (1-S)*I;
  } else if(H < 4.188787) {
    H = H - 2.09439;
    cos_h = cos(H);
    cos_1047_h = cos(1.047196667-H);
    g = S*I/3*(1+cos_h/cos_1047_h);
    b = S*I/3*(1+(1-cos_h/cos_1047_h));
    r = 0;
    w = (1-S)*I;
  } else {
    H = H - 4.188787;
    cos_h = cos(H);
    cos_1047_h = cos(1.047196667-H);
    b = S*I/3*(1+cos_h/cos_1047_h);
    r = S*I/3*(1+(1-cos_h/cos_1047_h));
    g = 0;
    w = (1-S)*I;
  }
  
  // Mapping Function from rgbw = [0:1] onto their respective ranges.
  // For standard use, this would be [0:1]->[0:0xFFFF] for instance.

  // Here instead I am going to try a parabolic map followed by scaling.  
  analogWrite(_redpin, 0xFFFF*r);
  analogWrite(_greenpin, 0xFFFF*g);
  analogWrite(_bluepin, 0xFFFF*b);
  analogWrite(_whitepin, 0xFFFF*w);
}

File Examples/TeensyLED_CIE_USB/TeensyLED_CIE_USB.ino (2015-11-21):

//**************************************************************************
//
// TeensyLED CIE Controller
// Copyright Brian Neltner 2015
// Version 0.3 - May 29, 2015
//
// This provides a state of the art library and some basic example code for
// using the TeensyLED Controller board to generate RGBW colors in full
// CIE LCH colorspace. This example sets the hue between 0 and 360 and rotates
// around the color wheel. This angle is intersected with the line drawn
// between the nearest two LEDs with their CIE colorspace u' and v' coefficients
// to calculate the correct weighting of the two arbitrary CIE defined light
// sources to get the target CIE LCH hue.
//
// Note that in this version, for simplicity I have put in a bias to the red
// angle so that the red LED is at 0 degrees. In actuality, the red LED at
// 623 nm has a CIE hue of 9.67 degrees, but I think this will be easier
// to understand since it more closely matches the likely user goals.
//
// The data to calculate the CIE values for each LED was calculated by
// digitizing the power spectra provided for the LZ7 series LED from LEDEngin
// so you will need to get your own if you use a different LED (or just don't
// worry about it). Color correction to account for different LED brightness
// is done using the lumen output specified in the datasheet.
//
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
//***************************************************************************

#include "LEDs.h"

#define propgain 0.001

// Define the physical LEDs and their CIE LUV color locations.
// u', v', maxvalue, physical pin
CIELED white(0.202531646, 0.469936709, (float)30/180, 9);
CIELED red(0.5137017676, 0.5229440531, (float)30/78, 6);
CIELED amber(0.3135687079, 0.5529418124, (float)30/60, 5);
CIELED green(0.0595846867, 0.574988823, (float)30/125, 22);
CIELED cyan(0.0306675939, 0.5170937486, (float)30/95, 3);
CIELED blue(0.1747943747, 0.1117834986, (float)30/30, 23);
CIELED violet(0.31, 0.1, (float)30/30, 4);

// Create the physical abstraction for the LED controller.
// Redpin, Greenpin, Bluepin, Whitepin, Resolution, Frequency.
RGBWLamp lamp(6, (float)30/78, 22, (float)30/125, 23, 1, 9, (float)30/180, 16, 183.106);

// Creates a blank HSI color.
HSIColor color;

// Creates a freerunning HSI Fader.
HSIFader fader(HSIColor(0, 1, 0), HSIColor(120, 1, 0), 1000, 0);

// Creates a freerunning strober.
HSIStrober strober(HSIColor(), HSIColor(), 1000);

void setup() {
  Serial.begin(115200);
  
  pinMode(white.getPin(), OUTPUT);
  pinMode(red.getPin(), OUTPUT);
  pinMode(amber.getPin(), OUTPUT);
  pinMode(green.getPin(), OUTPUT);
  pinMode(cyan.getPin(), OUTPUT);
  pinMode(blue.getPin(), OUTPUT);
  pinMode(violet.getPin(), OUTPUT);
    
  while(1) {
    analogWrite(violet.getPin(), 0);
    analogWrite(white.getPin(), 0xFFFF);
    delay(1000);
    analogWrite(white.getPin(), 0);
    analogWrite(red.getPin(), 0xFFFF);
    delay(1000);
    analogWrite(red.getPin(), 0);
    analogWrite(amber.getPin(), 0xFFFF);
    delay(1000);
    analogWrite(amber.getPin(), 0);
    analogWrite(green.getPin(), 0xFFFF);
    delay(1000);
    analogWrite(green.getPin(), 0);
    analogWrite(cyan.getPin(), 0xFFFF);
    delay(1000);
    analogWrite(cyan.getPin(), 0);
    analogWrite(blue.getPin(), 0xFFFF);
    delay(1000);
    analogWrite(blue.getPin(), 0);
    analogWrite(violet.getPin(), 0xFFFF);
    delay(1000);
  }
  
  // Wait a bit on startup to let the USB interface come up.
  delay(1000);
  
  lamp.begin();
  
  // Initialize to fully saturated red with no intensity.
  color.setHSI(0, 1, 0);
  lamp.setColor(color);
  
//  fader.setFader(HSIColor(0, 1, 0), HSIColor(120, 1, 1), 5000, 0);
//  while(fader.isRunning()) {
//    handleFade();
//  }
}

boolean updated = false;
enum mode {HSI = 0, Strobe = 1, Fade = 2} mode = HSI;
float strobe;
enum strobestate {on = 1, off = 0} strobestate = on;
float savedintensity;

void loop() {
  if (Serial.available()) evaluateCommand(Serial.readStringUntil(0x0D));
  
  switch (mode) {
    case 0: // Standard HSI mode.
      handleHSI();
      break;
    case 1: // Handle Strober mode.
      handleStrobe();
      break;
    case 2: // Fade HSI mode.
      handleFade();
      break;
  }
}

void handleHSI() {
  if (color.isupdated()) {
    lamp.setColor(color);
  }
}

void handleFade() {
  // If the fader is running, update it.
  if (fader.isRunning()) {
    HSIColor newcolor = fader.getHSIColor();
    lamp.setColor(newcolor);
  }
  // If the fader is done, set state back to HSI.
  else mode = HSI;
}

void handleStrobe() {
  HSIColor newcolor = strober.getHSIColor();
  lamp.setColor(newcolor);
}

void evaluateCommand(String commandstring) {
  if (commandstring.startsWith("HSI ")) {
    // If it matches HSI, delete the command and capture three floats.
    commandstring.replace("HSI ", "");
    // Next, find the 2 spaces between the floats.
    int spaceIndex = commandstring.indexOf(' ');
    if (spaceIndex != -1) {
      int spaceIndex2 = commandstring.indexOf(' ', spaceIndex + 1);
      if (spaceIndex2 != -1) {
        // Then check that the three values are floats.
        if (checkFloat(commandstring.substring(0, spaceIndex)) == 0) {
          if (checkFloat(commandstring.substring(spaceIndex+1, spaceIndex2)) == 0) {
            if (checkFloat(commandstring.substring(spaceIndex2+1)) == 0) {
              color.setHSI(commandstring.substring(0, spaceIndex).toFloat(), commandstring.substring(spaceIndex+1, spaceIndex2).toFloat(), commandstring.substring(spaceIndex2+1).toFloat());
              mode = HSI;
              updated = true;
              Serial.println("OK");
            }
            else Serial.println("ERROR");
          }
          else Serial.println("ERROR");
        }
        else Serial.println("ERROR");
      }
      else Serial.println("ERROR");
    }
    else Serial.println("ERROR");
  }
  // Strobe command. HSI value 1, HSI value 2, period.
  else if (commandstring.startsWith("Strobe ")) {
    commandstring.replace("Strobe ", "");
    // First find the six expected spaces.
    int spaceIndex = commandstring.indexOf(' ');
    if (spaceIndex != -1) {
      int spaceIndex2 = commandstring.indexOf(' ', spaceIndex + 1);
      if (spaceIndex2 != -1) {
        int spaceIndex3 = commandstring.indexOf(' ', spaceIndex2 + 1);
        if (spaceIndex3 != -1) {
          int spaceIndex4 = commandstring.indexOf(' ', spaceIndex3 + 1);
          if (spaceIndex4 != -1) {
            int spaceIndex5 = commandstring.indexOf(' ', spaceIndex4 + 1);
            if (spaceIndex5 != -1) {
              int spaceIndex6 = commandstring.indexOf(' ', spaceIndex5 + 1);
              if (spaceIndex6 != -1) {
                
                // Then check that the three values are floats.
                if (checkFloat(commandstring.substring(0, spaceIndex)) == 0) {
                  if (checkFloat(commandstring.substring(spaceIndex+1, spaceIndex2)) == 0) {
                    if (checkFloat(commandstring.substring(spaceIndex2+1, spaceIndex3)) == 0) {
                      if (checkFloat(commandstring.substring(spaceIndex3+1, spaceIndex4)) == 0) {
                        if (checkFloat(commandstring.substring(spaceIndex4+1, spaceIndex5)) == 0) {
                          if (checkFloat(commandstring.substring(spaceIndex5+1, spaceIndex6)) == 0) {
                            if (checkFloat(commandstring.substring(spaceIndex6+1)) == 0) {
                              unsigned long time = commandstring.substring(spaceIndex6+1).toFloat();
                              if (time > 0) {
                                // Then all the values are valid.
                                HSIColor color1(commandstring.substring(0, spaceIndex).toFloat(), commandstring.substring(spaceIndex+1, spaceIndex2).toFloat(), commandstring.substring(spaceIndex2+1, spaceIndex3).toFloat());
                                HSIColor color2(commandstring.substring(spaceIndex3+1, spaceIndex4).toFloat(), commandstring.substring(spaceIndex4+1, spaceIndex5).toFloat(), commandstring.substring(spaceIndex5+1, spaceIndex6).toFloat());
                                
                                strober.setStrober(color1, color2, time);
                                mode = Strobe;
                                Serial.println("OK");
                              }
                              else Serial.println("ERROR");
                            }
                            else Serial.println("ERROR");
                          }
                          else Serial.println("ERROR");
                        }
                        else Serial.println("ERROR");
                      }
                      else Serial.println("ERROR");
                    }
                    else Serial.println("ERROR");
                  }
                  else Serial.println("ERROR");
                }
                else Serial.println("ERROR");
              }
              else Serial.println("ERROR");
            }
            else Serial.println("ERROR");
          }
          else Serial.println("ERROR");
        }
        else Serial.println("ERROR");
      }
      else Serial.println("ERROR");
    }
    else Serial.println("ERROR");
  }
  
  else if (commandstring.startsWith("Fade ")) {
    commandstring.replace("Fade ", "");
    
    // First find the seven expected spaces.
    int spaceIndex = commandstring.indexOf(' ');
    if (spaceIndex != -1) {
      int spaceIndex2 = commandstring.indexOf(' ', spaceIndex + 1);
      if (spaceIndex2 != -1) {
        int spaceIndex3 = commandstring.indexOf(' ', spaceIndex2 + 1);
        if (spaceIndex3 != -1) {
          int spaceIndex4 = commandstring.indexOf(' ', spaceIndex3 + 1);
          if (spaceIndex4 != -1) {
            int spaceIndex5 = commandstring.indexOf(' ', spaceIndex4 + 1);
            if (spaceIndex5 != -1) {
              int spaceIndex6 = commandstring.indexOf(' ', spaceIndex5 + 1);
              if (spaceIndex6 != -1) {
                int spaceIndex7 = commandstring.indexOf(' ', spaceIndex6 + 1);
                if (spaceIndex7 != -1) {
                
                  // Then check that the three values are floats.
                  if (checkFloat(commandstring.substring(0, spaceIndex)) == 0) {
                    if (checkFloat(commandstring.substring(spaceIndex+1, spaceIndex2)) == 0) {
                      if (checkFloat(commandstring.substring(spaceIndex2+1, spaceIndex3)) == 0) {
                        if (checkFloat(commandstring.substring(spaceIndex3+1, spaceIndex4)) == 0) {
                          if (checkFloat(commandstring.substring(spaceIndex4+1, spaceIndex5)) == 0) {
                            if (checkFloat(commandstring.substring(spaceIndex5+1, spaceIndex6)) == 0) {
                              if (checkFloat(commandstring.substring(spaceIndex6+1, spaceIndex7)) == 0) {
                                if (checkInt(commandstring.substring(spaceIndex7+1)) == 0) {
                                  unsigned long time = commandstring.substring(spaceIndex6+1, spaceIndex7).toFloat();
                                  if (time > 0) {
                                    // Then all the values are valid.
                                    HSIColor color1(commandstring.substring(0, spaceIndex).toFloat(), commandstring.substring(spaceIndex+1, spaceIndex2).toFloat(), commandstring.substring(spaceIndex2+1, spaceIndex3).toFloat());
                                    HSIColor color2(commandstring.substring(spaceIndex3+1, spaceIndex4).toFloat(), commandstring.substring(spaceIndex4+1, spaceIndex5).toFloat(), commandstring.substring(spaceIndex5+1, spaceIndex6).toFloat());
                                    byte direction = commandstring.substring(spaceIndex7+1).toInt();
                                    fader.setFader(color1, color2, time, direction);
                                    mode = Fade;
                                    Serial.println("OK");
                                  }
                                  else Serial.println("ERROR");
                                }
                                else Serial.println("ERROR");
                              }
                              else Serial.println("ERROR");
                            }
                            else Serial.println("ERROR");
                          }
                          else Serial.println("ERROR");
                        }
                        else Serial.println("ERROR");
                      }
                      else Serial.println("ERROR");
                    }
                    else Serial.println("ERROR");
                  }
                  else Serial.println("ERROR");
                }
                else Serial.println("ERROR");
              }
              else Serial.println("ERROR");
            }
            else Serial.println("ERROR");
          }
          else Serial.println("ERROR");
        }
        else Serial.println("ERROR");
      }
      else Serial.println("ERROR");
    }
    else Serial.println("ERROR");
  }
}

int checkFloat(String data) {
  // The simplest way to go about testing the string for only numerical inputs
  // since Arduino doesn't implement regex, is probably to count the number of 
  // characters and then count the number of instances of each valid number
  // character. i.e. [0-9] and the decimal point for a float after trimming
  // whitespace or newlines.
  
  data.trim();
  // Check to make sure the string isn't now blank.
  if (data.length() == 0) return -2;
  
  unsigned int runningtotal = 0;
  
  for (unsigned int j=0; j<data.length(); j++) {
    char activechar = data.charAt(j);
    // Test against valid cahracter list.
    if ((activechar == '-') ||
        (activechar == '.') ||
        (activechar == '0') ||
        (activechar == '1') ||
        (activechar == '2') ||
        (activechar == '3') ||
        (activechar == '4') ||
        (activechar == '5') ||
        (activechar == '6') ||
        (activechar == '7') ||
        (activechar == '8') ||
        (activechar == '9')) runningtotal++;
  }
  
  if (runningtotal == data.length()) return 0;
  else return -1;
}

int checkInt(String data) {
  // The simplest way to go about testing the string for only numerical inputs
  // since Arduino doesn't implement regex, is probably to count the number of 
  // characters and then count the number of instances of each valid number
  // character. i.e. [0-9] and the decimal point for a float after trimming
  // whitespace or newlines. Oh, plus the negative sign.
  
  data.trim();
  
  int runningtotal = 0;
  
  for (int j=0; j<data.length(); j++) {
    char activechar = data.charAt(j);
    // Test against valid cahracter list.
    if ((activechar == '-') ||
        (activechar == '0') ||
        (activechar == '1') ||
        (activechar == '2') ||
        (activechar == '3') ||
        (activechar == '4') ||
        (activechar == '5') ||
        (activechar == '6') ||
        (activechar == '7') ||
        (activechar == '8') ||
        (activechar == '9')) runningtotal++;
  }
  
  if (runningtotal == data.length()) return 0;
  else return -1;
}

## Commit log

2015-04-18 added eagle files.
    [TeensyLED 15041702.brd, TeensyLED 15041702.sch]
2015-04-21 added simulations, updated board design, and updated README.
    [TeensyLED 15042100.brd, TeensyLED 15042100.sch]
2015-04-21 cleaned things up, testing readme.md inline images...
    [TeensyLED 15041702.brd, TeensyLED 15041702.sch, TeensyLED.brd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]
2015-04-21 added link to schematic and board pdf file.
2015-04-21 added image of board for display.
2015-05-20 updated board and new simulations.
2015-05-21 updated board design and project description
    [TeensyLED.brd, TeensyLED.sch]
